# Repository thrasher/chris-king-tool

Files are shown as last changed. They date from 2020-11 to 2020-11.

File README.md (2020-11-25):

# Chris King Tools

## Summary

Bearing pre-load tool based on the Chris King [Cone Adjusting Tool](https://chrisking.com/collections/hub-tools/products/cone-adjusting-tool).

Video Demo (https://www.youtube.com/watch?v=-1BgzFUTxxI)
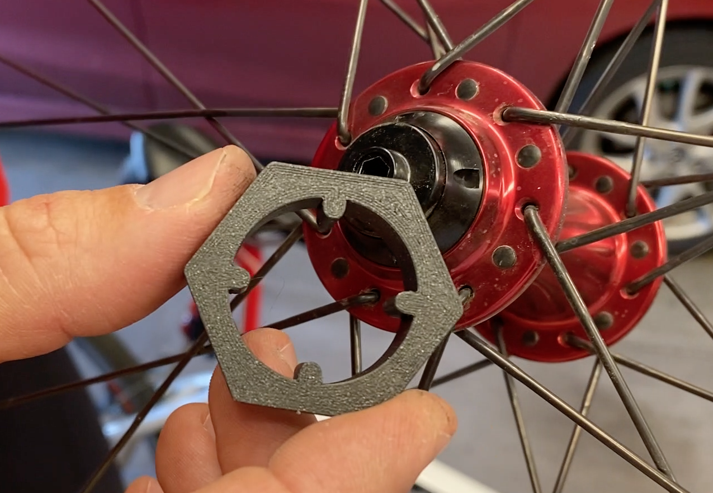
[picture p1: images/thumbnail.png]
tool demonstration 3D Printed Cone Adjusting Tool (https://www.youtube.com/watch?v=-1BgzFUTxxI)


## Print Settings

Print on draft mode w/0.3mm layer height to get a stronger part.
Insure that there are enough shells to fill the width of the pins solid (the pins must be strong).

## Post-Printing Installation

To adjust the R45 front hub:
1. Per [Chris King Quick Release Front Hub Adjustment](https://www.youtube.com/watch?v=EI9qNj4CjPM), use a vise to loosen the two 5mm ends of the hub.
1. Use the tool to tighten the adjusting cone finger tight. The axel should spin freely without play.
1. Torque axle end to 110in lbs. (12.4 Nm). Hold the adjusting cone in place while tightening.
1. Go ride it.

## How I Designed This

Manually took measurements off of my Chris King R45 front hub.

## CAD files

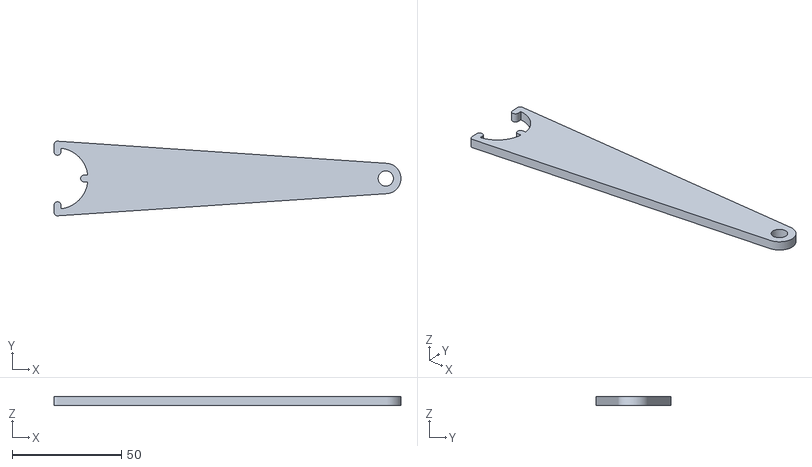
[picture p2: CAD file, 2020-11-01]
chrisking_front_wrench.stl
158.5 x 34.1 x 4.00

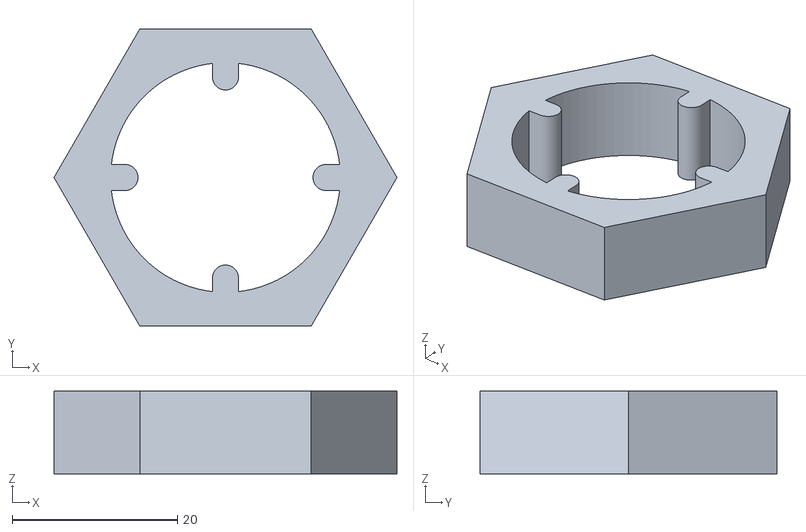
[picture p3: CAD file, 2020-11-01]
chrisking_front_socket.stl
41.6 x 36.0 x 10.0

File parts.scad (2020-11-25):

// all dimensions in millimeters
// see: https://en.wikibooks.org/wiki/OpenSCAD_User_Manual/Other_Language_Features#$fa,_$fs_and_$fn
$fs = 2; // minimum size of a circle fragment, default=2, min=0.01
$fa = 15; // a circle has fragments = 360 divided by this number, default=12, min=0.01
$fn = $preview ? 24 : 80; // number of fragments in a circle, when non-zero $fs and $fa are ignored, default=0

MIN_SPACING = 21.2; // 21.2 diameter as measured between pin cuts on hub
ADJUSTER_DIA = 27.84; // 27.84 diameter of frunt hub adjuster as measured
PIN_DIA = 3.15; // 3.15 as measured size of pin on front hub
PIN_HEIGHT = 4;
BODY_DEPTH = 10;
TOOL_THICKNESS = 4;
PIN_RADIUS = (MIN_SPACING + PIN_DIA) / 2;

module pin(h = 4) {
	hull() {
		// pin location
		translate([PIN_RADIUS, 0, 0])
		cylinder(d = PIN_DIA, h = h);
		// tool body
		TB_DIA = (ADJUSTER_DIA + PIN_DIA) / 2;
		translate([TB_DIA, 0, 0])
		cylinder(d = PIN_DIA, h = h);
	}
}
module pins(h = 4) {
	pin(h); // center
	mirror([1,1,0]) pin(h); // bottom
	mirror([1,-1,0]) pin(h); // top
}

module front_socket() {
	pin(10); // center
	mirror([1,1,0]) pin(10); // bottom
	mirror([1,-1,0]) pin(10); // top
	mirror([1,0,0])pin(10); // center

	// cut out space where the pins go
	difference() {
		color("purple") linear_extrude(10) circle(r = 18/cos(180/6), $fn=6);
		cylinder(d = ADJUSTER_DIA, h = TOOL_THICKNESS*6, center = true);
		// cylinder(d = MIN_SPACING, h = 15);
	}
}

module front_wrench() {
	difference() {
		// main handle
		hull() {
			pins();
			// cylinder(d = BODY_DEPTH * 2 + ADJUSTER_DIA, h = TOOL_THICKNESS);
			translate([150, 0, 0])
			cylinder(d = ADJUSTER_DIA/2, h = TOOL_THICKNESS);
		}

		// cut out space where the pins go
		cylinder(d = ADJUSTER_DIA, h = TOOL_THICKNESS*3, center = true);

		// logo to know what the tool is for
		logo();

		// hole for hanging tool
		translate([150, 0, 0])
		cylinder(d = ADJUSTER_DIA/4, h = TOOL_THICKNESS * 3, center = true);

		// cut small version of tool w/just the head for test print
		// translate([75 + 18, 0, 0])
		// cube(150, center = true);
	}


	// add the pins back in
	pins();

	module logo() {
		translate( [ADJUSTER_DIA/2+10, -7.5, TOOL_THICKNESS])
		linear_extrude(height = 1, center = true, convexity = 10, twist = 0, slices = 20, scale = 1.0)
		scale(1.5)
		import("images/ck-primary-white-w_800x.svg", center = false, dpi = 100);
	}
}

PART = "all";
if (PART == "front_wrench" || PART == "all") {
	echo(str("render ", PART));
	front_wrench();
}
if (PART == "front_socket" || PART == "all") {
	echo(str("render ", PART));
	translate([0, 40, 0])
	front_socket();
}

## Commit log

2020-11-01 created Chris King hub adjustment tool
    [chrisking_front_socket.stl, chrisking_front_wrench.stl, parts.scad]
2020-11-25 adding video link, moving images to subdir
    [parts.scad]
